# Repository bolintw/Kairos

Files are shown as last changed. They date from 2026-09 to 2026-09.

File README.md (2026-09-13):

# Kairos

<p align="center">
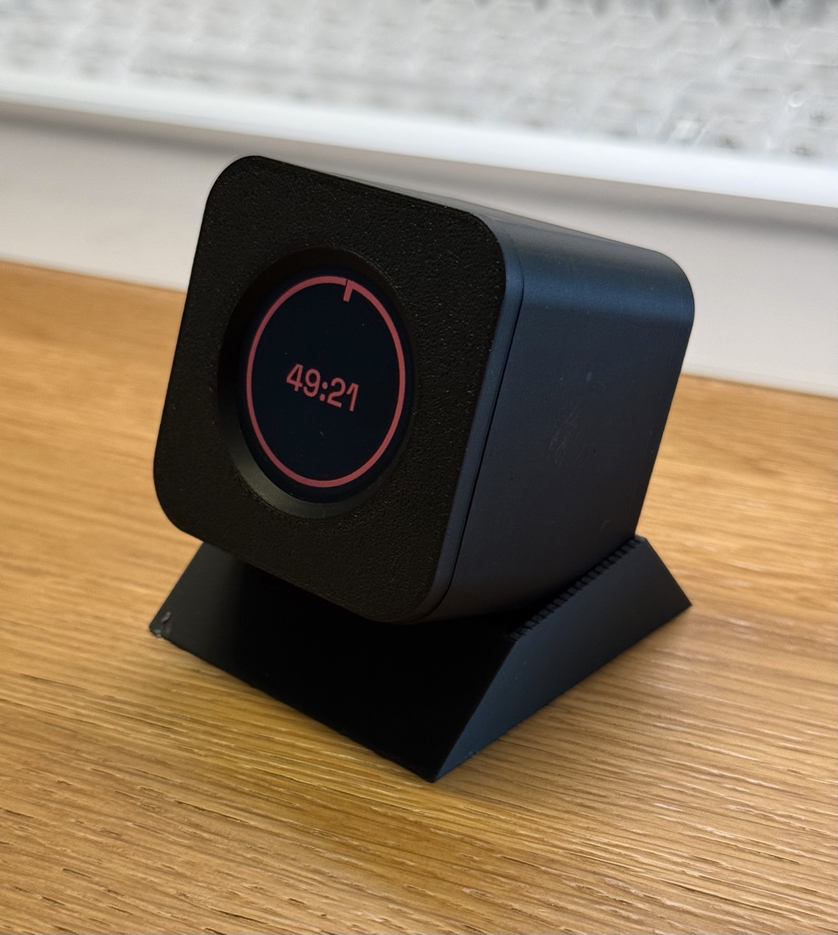
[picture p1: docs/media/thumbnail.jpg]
Kairos on a desk
  
</p>

A gravity-triggered desktop Pomodoro / countdown timer. No buttons for the
core interaction — flip the device to a different face to switch what it's
timing, tap it to start or pause. Built on a Waveshare ESP32-S3-LCD-1.28
round display, in modern C++ on ESP-IDF.

Kairos is also a personal practice ground for two things at once: getting
hands-on with embedded C++ on real hardware, and calibrating how well an AI
coding agent (Claude) holds up on a project that grows past a single
session — architecture discipline, whether its design choices survive
contact with real hardware bugs, and how to review its output in a domain
I'm not already fluent in. Every commit that's been verified on real
hardware and authored primarily by the agent is committed under
`Claude Sonnet 5 <noreply@anthropic.com>`, so that history is easy to
filter and read back later (`git log --author="Claude Sonnet 5"`).

## Faces

The device has no fixed "up" — the screen always faces you, and you rotate
it in your hand like a dial. Four quadrants each hold a different timer:

| Face | Mode |
|---|---|
| A | Pomodoro, 25 min focus / 5 min break |
| B | Pomodoro, 50 min focus / 10 min break |
| C | Stopwatch (counts up, no target duration) |
| D | Breathe — a guided 4-7-8 breathing exercise, four rounds that ramp up to the full pattern |

Rotating past a hysteresis threshold switches which face is active and
resets that face's progress. Screen brightness doubles as the notification
channel — it fades during a focus session, snaps back on any interaction,
and ramps up again as a phase is about to end — since there's no speaker or
vibration motor.

**Battery view**: not a fifth face — pick the device up and hold it tilted
out of its normal resting plane for about half a second, and the screen
swaps to a 5-segment battery gauge instead of whatever face was showing.
Set it back down (or lay it flat again) and it returns immediately. The
timer underneath keeps running the whole time.

## Controls

**Single tap** — start or pause whichever face is currently showing.

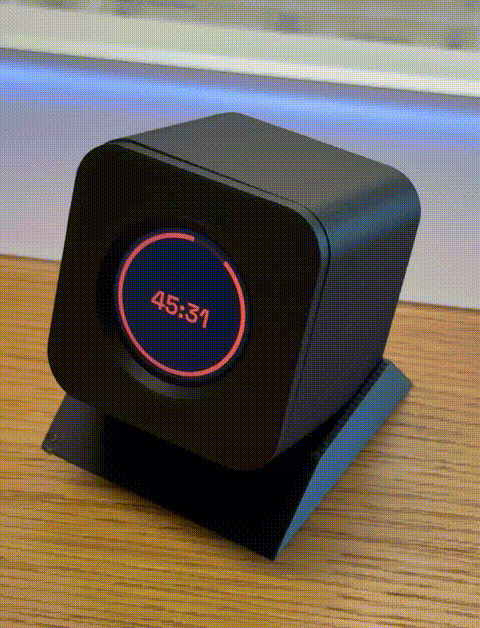
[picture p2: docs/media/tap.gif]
Tap to start/pause


**Flip** — rotate to a different face to switch what's being timed.

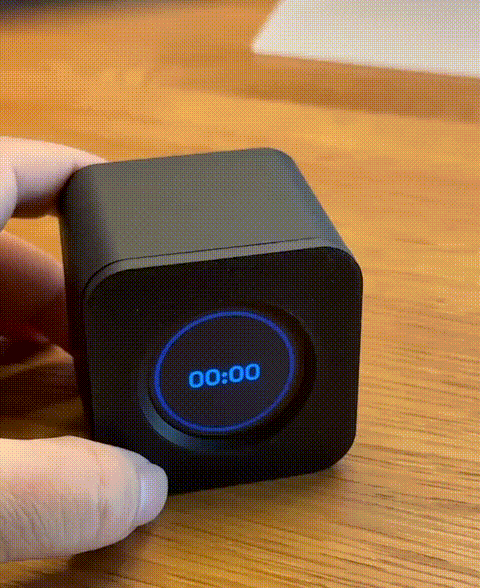
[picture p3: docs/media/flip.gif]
Flip to switch faces


**Double tap** — wakes the screen from idle sleep, a deliberate two-tap
gesture so an incidental bump won't wake it by accident.

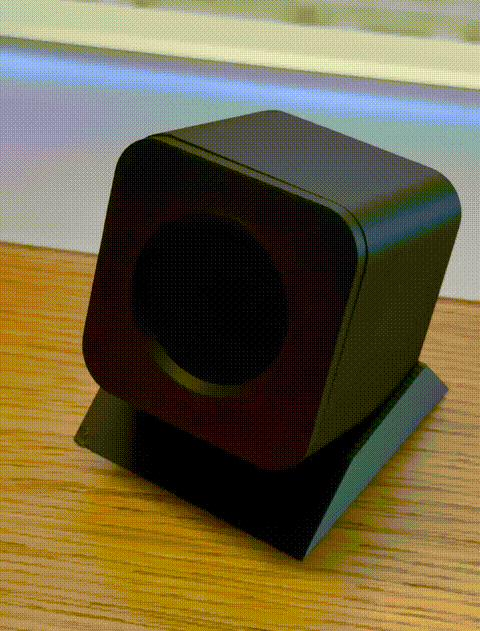
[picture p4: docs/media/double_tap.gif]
Double tap to wake from sleep


**Hold BOOT (~3s)** — enters calibration mode, while the device is already
running.

## Hardware

- [Waveshare ESP32-S3-LCD-1.28](https://www.waveshare.com/esp32-s3-lcd-1.28.htm) — round 240×240 GC9A01A SPI display, QMI8658 6-axis IMU, ESP32-S3, in one non-touch board.
- One or two 800mAh 1S LiPo cells. Two wired in parallel (~1600mAh combined) is a drop-in upgrade — electrically it's still a single 1S pack to the charger and firmware.

## Battery Life

Measured current draw:

| State | Current |
|---|---|
| Full brightness (paused / just interacted) | ~82mA |
| Dimmed (running, immersion-faded) | ~70mA |
| Idle sleep (light sleep, screen off) | ~800µA |

The firmware also runs a two-stage low-battery safety net — a forced
warning screen first, then automatic deep sleep to protect the cell from
over-discharge if it's left unattended.

Real-hardware endurance test on a single 800mAh cell, kept continuously
active the entire time (never allowed to idle-sleep — the worst case for
power draw): **10 hours 10 minutes** before the low-battery warning
triggered. Day-to-day use, dominated by light sleep between interactions,
runs considerably longer than this.

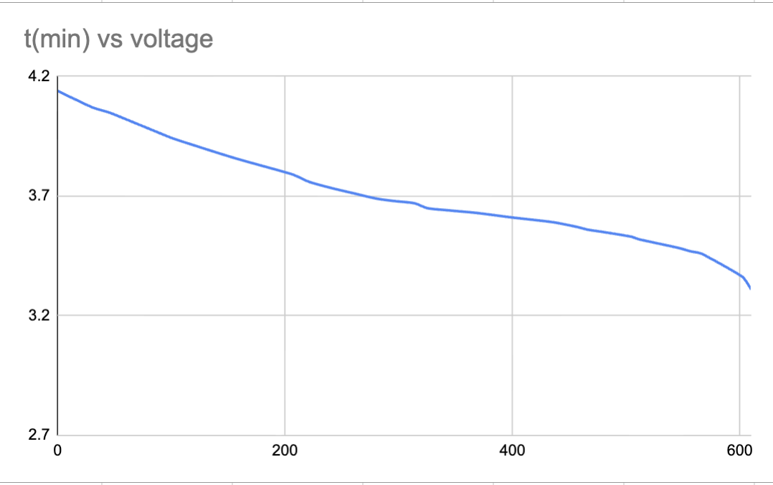
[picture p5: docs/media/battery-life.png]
Battery voltage vs. time over the 10h10m endurance test


## Assembly

Printable files: [Kairos — Gravity Timer on MakerWorld](https://makerworld.com/zh-tw/models/3299098-kairos-gravity-timer-homemade-pomodoro-cube#profileId-3744041).

What you'll need, beyond the printed front cover, back cover, and button:

- 4× M3 × 4mm heat-set threaded inserts
- 4× M3 × 5mm countersunk (flat-head) screws
- 4× strong magnets, 8mm diameter × 2mm thick

Steps:

1. Print the parts. Pause the print at the marked layer(s) to embed the
   magnets, then resume — printing everything in one job means two pauses
   in total.
2. Heat-set the four threaded inserts into the printed front cover with a
   soldering iron.
3. Connect the battery cable to the screen, then set the screen onto the
   front cover.

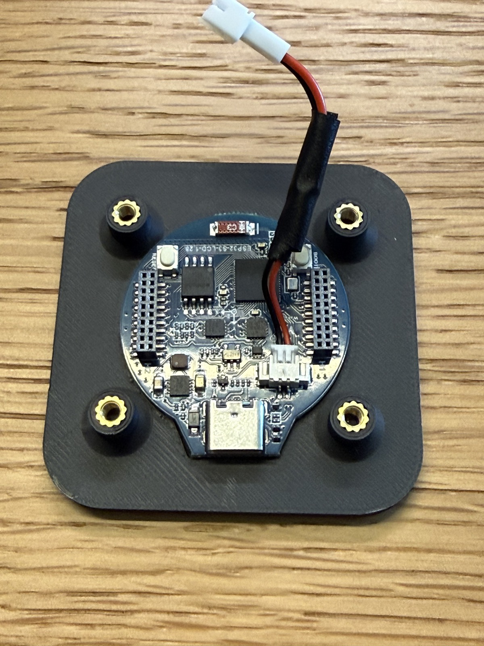
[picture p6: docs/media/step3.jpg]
Screen connected and seated on the front cover
   

4. Fit the printed button into its slot in the back cover. Flip it over
   onto the screen — the alignment tabs on either side capture the
   pin-header socket — and fasten with the four countersunk screws. Be
   careful the button doesn't fall out of place; if it helps, flip the
   screen/front-cover assembly over and lower it onto the back cover
   instead.

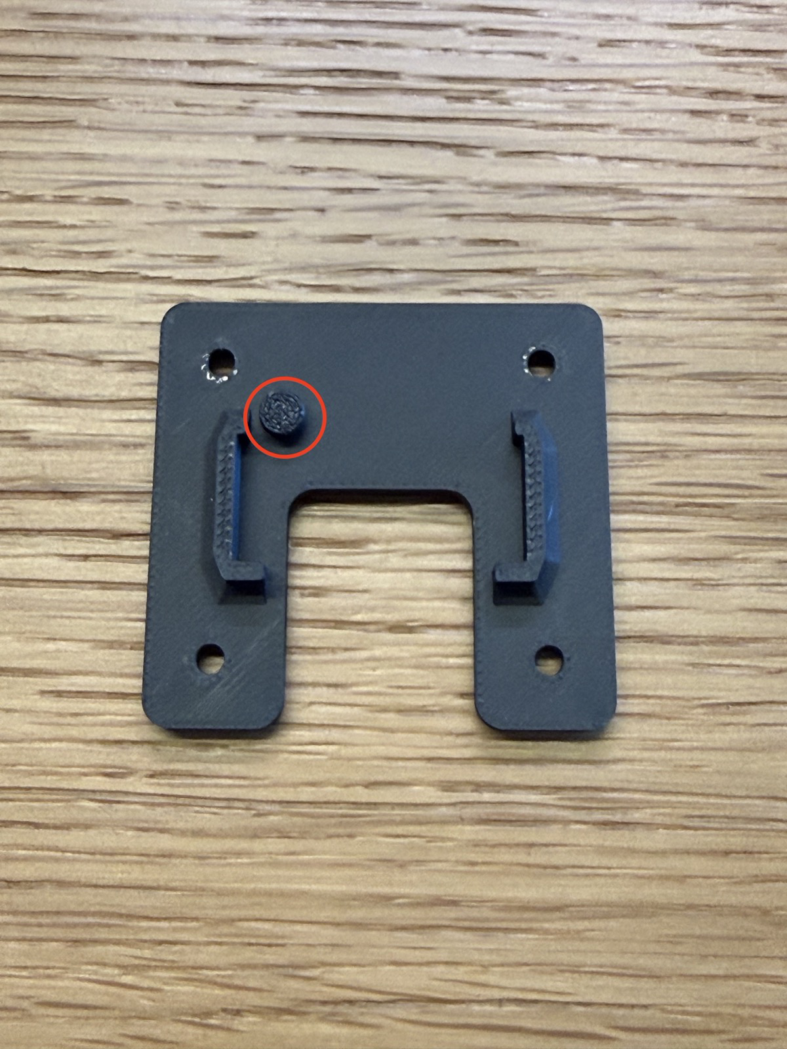
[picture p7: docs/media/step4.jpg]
Printed button seated in the back cover
   

5. Fit a battery inside the enclosure — double-sided tape works well to
   hold it in place. Use the largest capacity that still fits.

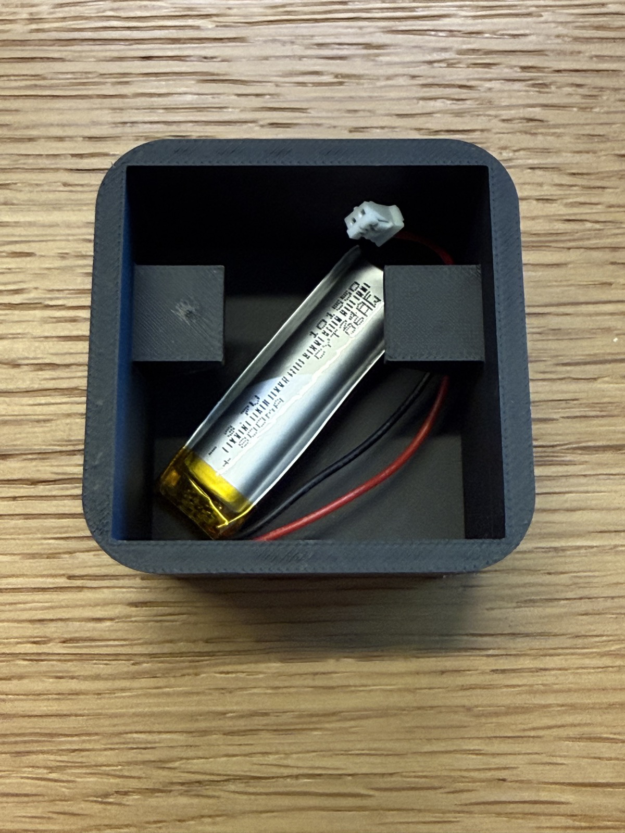
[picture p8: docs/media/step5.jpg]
Battery fitted inside the enclosure
   

6. Connect the battery, then close the front cover, aligning it to the
   magnets.

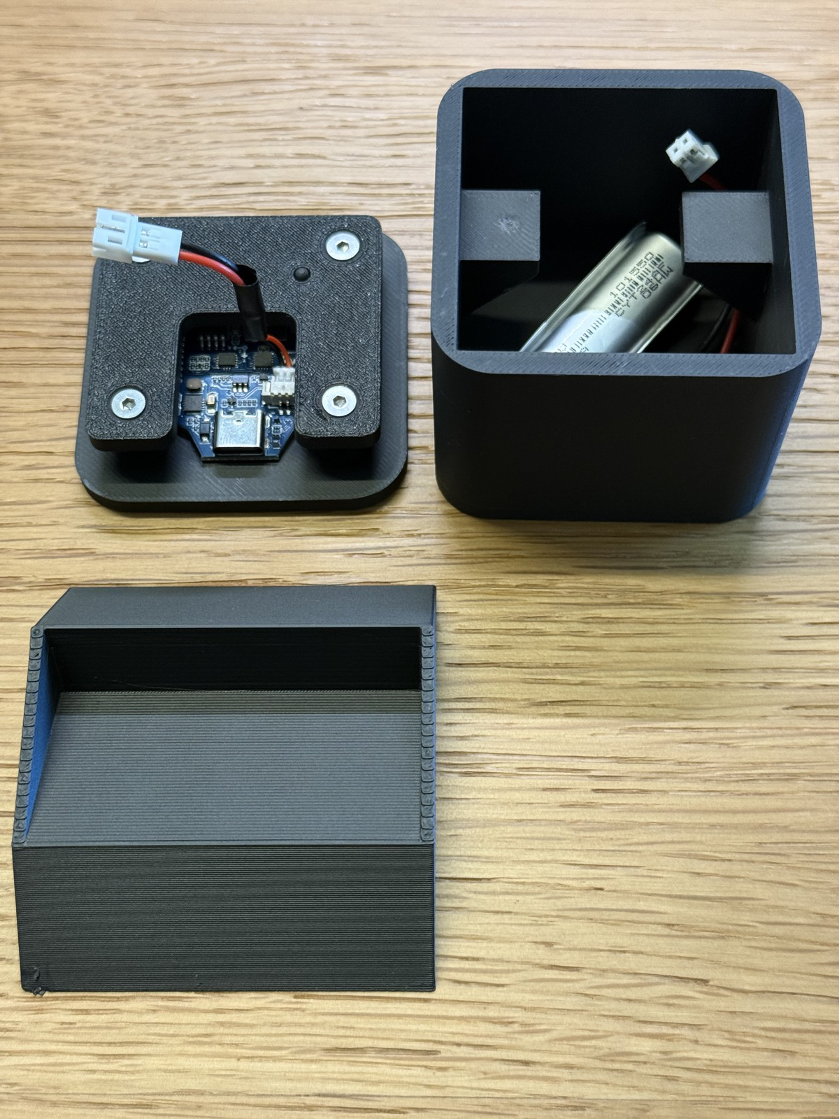
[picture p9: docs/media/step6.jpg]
Screen module, body, and front cover ready to close up
   
7. Once the screen looks correct, open the front cover, press and hold
   the calibration button, close the front cover again, and follow the
   on-screen prompts to calibrate.
8. Set it on the stand — enjoy!

## Building the Firmware

Requires [ESP-IDF](https://docs.espressif.com/projects/esp-idf/en/stable/esp32s3/get-started/index.html) v6.0 targeting `esp32s3`.

```sh
git submodule update --init --recursive
cd firmware
idf.py set-target esp32s3
idf.py build
idf.py -p <PORT> flash monitor
```

## License

[PolyForm Noncommercial 1.0.0](LICENSE) — free to use and modify for any
noncommercial purpose; commercial use is not permitted.

The primary display font is [Space Grotesk](https://github.com/floriankarsten/space-grotesk),
Copyright 2020 The Space Grotesk Project Authors, licensed under the
[SIL Open Font License 1.1](firmware/main/SpaceGrotesk-OFL.txt).

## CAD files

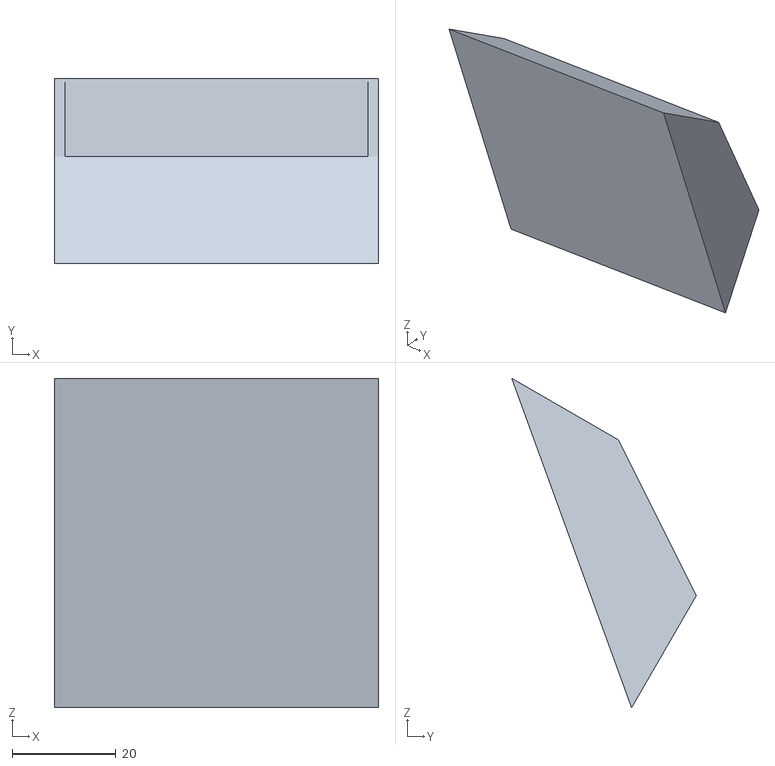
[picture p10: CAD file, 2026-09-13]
docs/printable/Stand.stl
62.4 x 35.6 x 63.5

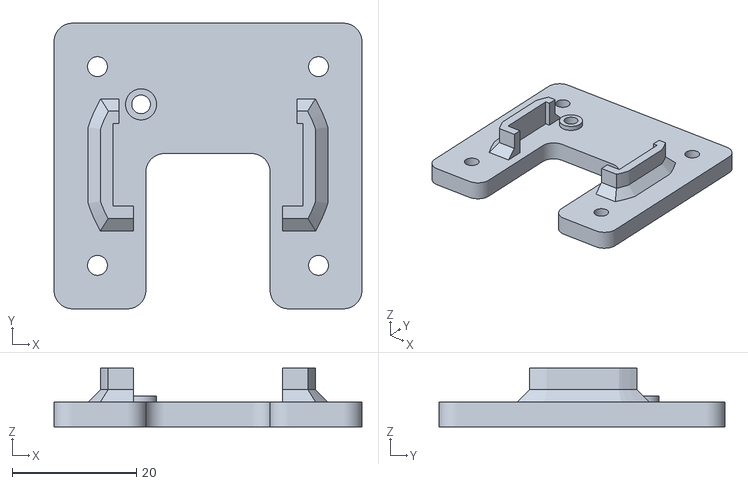
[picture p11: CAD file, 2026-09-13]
docs/printable/Display fixture.stl
49.6 x 46.0 x 9.50

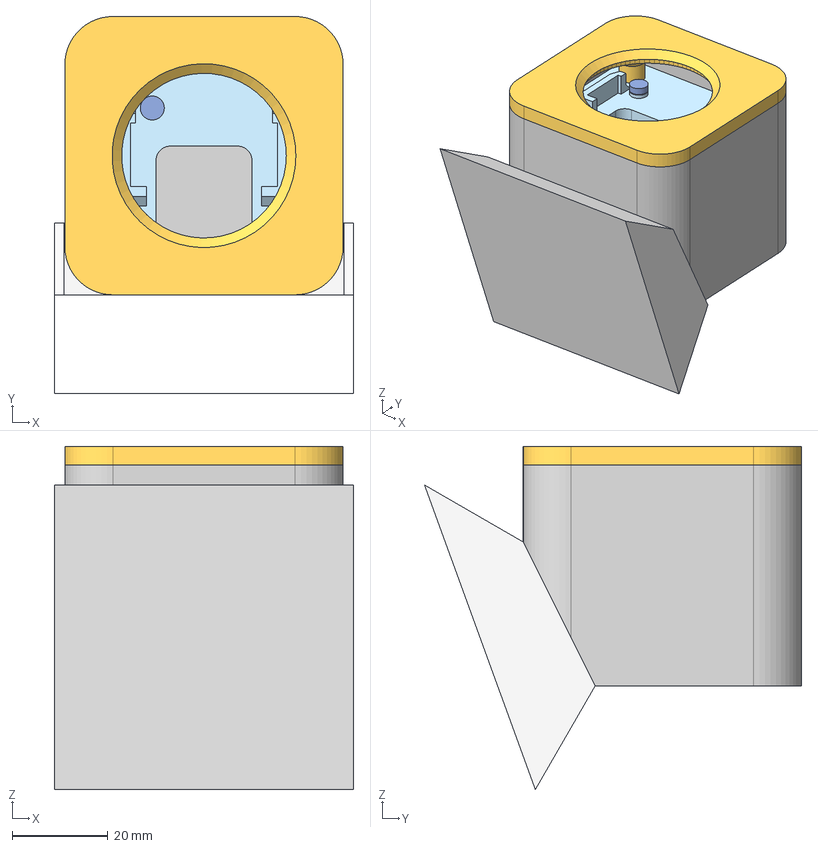
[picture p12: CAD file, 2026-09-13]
docs/printable/Kairos.step
62.4 x 78.6 x 71.5 mm

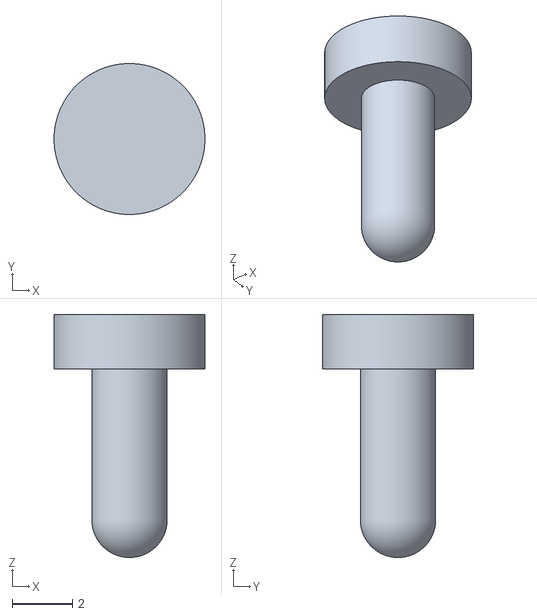
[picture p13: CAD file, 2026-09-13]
docs/printable/Button.stl
5.00 x 5.00 x 8.05

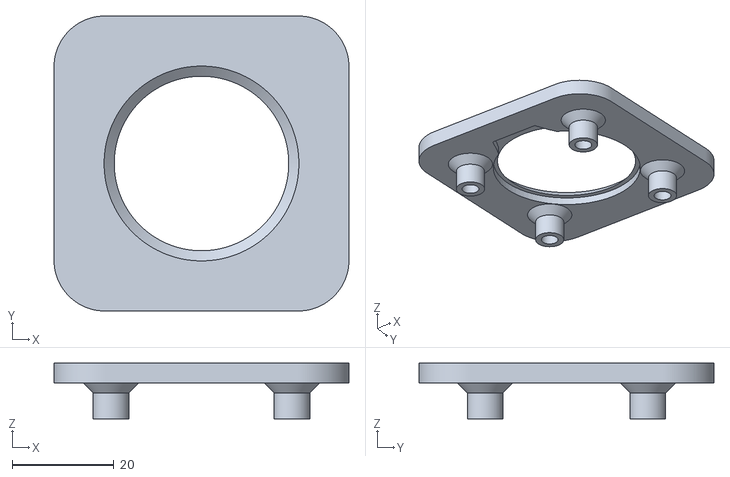
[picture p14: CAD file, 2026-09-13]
docs/printable/Front lid.stl
58.0 x 58.0 x 11.0

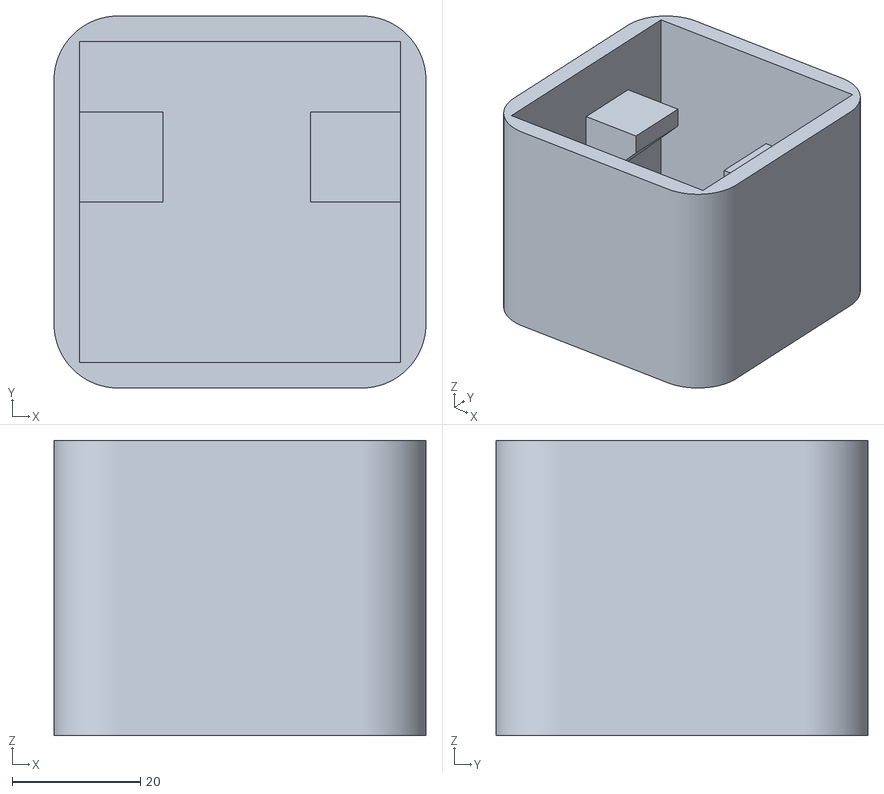
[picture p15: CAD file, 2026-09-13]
docs/printable/Box.stl
58.0 x 58.0 x 46.0

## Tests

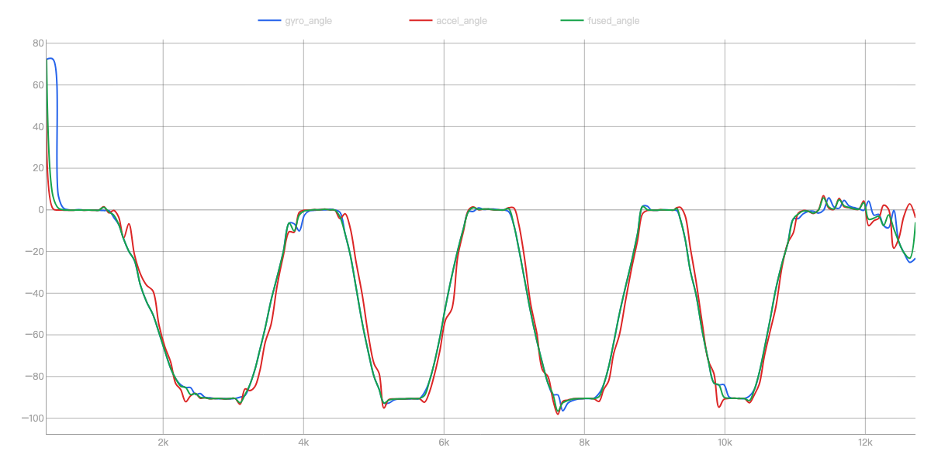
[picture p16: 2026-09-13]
docs/media/angle-test.png

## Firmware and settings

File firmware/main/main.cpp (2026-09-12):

#include <atomic>
#include <cstdint>
#include <cstdio>

#include "driver/gpio.h"
#include "esp_attr.h"
#include "esp_pm.h"
#include "esp_sleep.h"
#include "esp_timer.h"
#include "freertos/FreeRTOS.h"
#include "freertos/task.h"
#include "lvgl.h"
#include "nvs_flash.h"

#include "app_controller.hpp"
#include "attitude_estimator.hpp"
#include "battery_monitor.hpp"
#include "calibration_mode.hpp"
#include "debug_config.hpp"
#include "sleep_mode.hpp"
#include "gui_manager.hpp"
#include "i2c_scan.hpp"
#include "lgfx_config.hpp"
#include "nvs_calibration.hpp"
#include "qmi8658.hpp"

namespace {

constexpr int kLvglTickPeriodMs = 5;
// Two draw buffers enable LVGL's double-buffered partial mode: while
// chunk N is being DMA'd out over SPI, LVGL renders chunk N+1 into the
// other buffer instead of waiting.
constexpr int kDrawBufRows = 60;
// Sampling faster than what's filtered/displayed leaves headroom for the
// low-pass filters above the display's ~60fps cap. QMI8658's own ODR is
// 1000Hz and the I2C read itself is well under a millisecond, so 120Hz
// polling fits comfortably in the 5ms main-loop cadence.
constexpr int64_t kSensorUpdatePeriodUs = 1000000 / 120;  // ~120Hz

// A voltage reading has no reason to be as fresh as attitude — voltage
// drifts on a minutes scale, and BatteryMonitor::ReadVoltage() already
// blocks for kNumSamples (32) raw ADC reads per call.
constexpr int64_t kBatteryReadPeriodUs = 10 * 1000000;  // 0.1Hz

// Stage 2 of the low-battery safety net — see app_controller.hpp design
// note 11 for stage 1 (the warning screen, down to kLowBatteryEnterV).
// Below this second, lower threshold, refuse to keep running at all:
// forced deep sleep instead of the normal light-sleep+WoM loop — see the
// idle-sleep block below. Enter threshold is
// AppController::kCriticalBatteryEnterV (3.0V), read from there rather
// than duplicated here so the two constants can't drift apart.
//
// Exit threshold is set far above entry (3.8V, not e.g. 3.2V) because a
// LiPo's terminal voltage jumps up a real step the instant charging
// current starts flowing, before any meaningful capacity has gone back
// in (internal-resistance IR drop, not state of charge — and a degraded
// cell's higher internal resistance makes this jump bigger, not
// smaller). A narrow gap risks reading that transient alone as
// "recovered" and resuming full active operation while the battery's
// real stored energy has barely moved.
constexpr float kCriticalBatteryExitV = 3.8f;
// Deep sleep current is tiny (~8uA) next to a brief active-boot check,
// so this can afford to be fairly frequent.
constexpr uint64_t kCriticalBatteryCheckPeriodUs = 30ULL * 1000 * 1000;

// Hides the debug overlay (angle/taps/is_moving label) without deleting
// the code.
constexpr bool kDebugOverlayEnabled = kDebugEnabled;

// One live "ATT," CSV line per sensor tick with AttitudeEstimator's
// gyro-only angle, accel-only angle, fused angle, and gz.
constexpr bool kAttitudeDebugLogEnabled = false;

// Hold BOOT (GPIO0) this long, while the app is already running, to enter
// calibration mode. NOT checked at power-on/reset — see calibration_mode.hpp.
constexpr int64_t kCalibrationHoldUs = 3 * 1000 * 1000;

// Tap Engine config — see qmi8658.hpp's ConfigureTap() for what each
// parameter means. The idle-sleep path (Qmi8658::SetLowPowerAccelOnly())
// deliberately leaves the accel ODR these were tuned against unchanged,
// so these same values keep applying whether or not gyro is enabled.
constexpr uint8_t kTapPriority = 0;
constexpr uint8_t kTapPeakWindow = 40;
constexpr uint16_t kTapTapWindow = 100;
constexpr uint16_t kTapDTapWindow = 500;
constexpr float kTapAlpha = 0.0625f;
constexpr float kTapGamma = 0.25f;
constexpr float kTapPeakMagThr = 0.8f;
constexpr float kTapUdmThr = 0.4f;

// Wake-on-Motion config for idle sleep — see qmi8658.hpp's
// EnterWakeOnMotion(). kWomThresholdMg is maxed out at the register's
// 255 ceiling — even there, WoM wakes on any sufficiently large
// accelerometer slope, not specifically a deliberate tap (see that
// method's trade-off note), which is why the two-stage confirm below
// exists as a software-side filter on top. kWomBlankingSamples is also
// maxed (6-bit field, max 63, ~63ms at 1000Hz accel ODR) to absorb the
// transient STATUS1 latch that toggling CTRL7 on mode entry can cause.
constexpr uint8_t kWomThresholdMg = 255;
constexpr uint8_t kWomBlankingSamples = 63;

// Two-stage WoM wake confirmation — see the idle-sleep block's own
// comment. A deliberate double-tap-to-wake gesture, not just a debounce:
// a single physical tap only ever registers on whichever detector is
// active at that instant (WoM, since the tap engine isn't running during
// light sleep), so this window waits for a genuinely separate second
// tap. 1500ms gives a natural two-tap rhythm enough room, confirmed
// reliable both bare-board and inside the finished enclosure.
constexpr int kWomConfirmWindowMs = 1500;
constexpr int kWomConfirmPollMs = 20;

// Measures the real elapsed time from RunIdleSleep() returning to the
// confirm-window poll loop starting — the cost of
// ExitWakeOnMotion()+ConfigureTap()+the spurious-latch discard.
constexpr bool kWomConfirmLatencyLogEnabled = kDebugEnabled;

static LGFX lcd;
static uint8_t lvgl_draw_buf1[240 * kDrawBufRows * 2];  // RGB565, 2 bytes/px
static uint8_t lvgl_draw_buf2[240 * kDrawBufRows * 2];

int64_t g_lvgl_flush_accum_us = 0;
uint32_t g_lvgl_flush_call_count = 0;

void lvgl_flush_cb(lv_display_t* disp, const lv_area_t* area, uint8_t* px_map)
{
    const int32_t w = area->x2 - area->x1 + 1;
    const int32_t h = area->y2 - area->y1 + 1;
    const int64_t flush_start_us = esp_timer_get_time();
    // Display is configured LV_COLOR_FORMAT_RGB565_SWAPPED to match the
    // byte order pushImage() expects.
    //
    // pushImageDMA() + waitDMA(): with two draw buffers, LVGL alternates
    // between them each flush, so while this chunk's bytes are still
    // going out over SPI, LVGL can render the next chunk into the other
    // buffer instead of blocking. waitDMA() at the top, not the bottom,
    // blocks only on the *previous* transfer if it hasn't finished yet —
    // this call's own transfer is left running and collected by the next
    // call's waitDMA() instead.
    lcd.waitDMA();
    lcd.pushImageDMA(area->x1, area->y1, w, h, reinterpret_cast<uint16_t*>(px_map));
    g_lvgl_flush_accum_us += esp_timer_get_time() - flush_start_us;
    ++g_lvgl_flush_call_count;
    lv_display_flush_ready(disp);
}

void lvgl_tick_cb(void*)
{
    lv_tick_inc(kLvglTickPeriodMs);
}

// LVGL's default builtin sprintf doesn't implement %f (it silently drops
// the conversion and leaves the literal 'f' character), so format floats
// as fixed-point integers ourselves rather than depend on a float-capable
// sprintf/libc combination.
int RoundToFixed(float value, int scale)
{
    return static_cast<int>(value * scale + (value >= 0 ? 0.5f : -0.5f));
}

// Splits a fixed-point value into sign + whole + fractional digits for
// display. Needed because plain `fixed / scale` truncates toward zero:
// for fixed=-85, scale=100, that gives whole=0 with no sign information
// left in it, so "%+d" on the whole part alone prints "+0" — silently
// hiding the sign on every reading with magnitude under 1.0. Splitting
// off the sign before dividing the (now always non-negative) magnitude
// avoids that.
struct FixedParts { char sign; int whole; int frac; };

FixedParts SplitFixed(int fixed, int scale)
{
    const int mag = fixed < 0 ? -fixed : fixed;
    return FixedParts{fixed < 0 ? '-' : '+', mag / scale, mag % scale};
}

// AttitudeEstimator deliberately doesn't include qmi8658.hpp (no
// hardware/I2C knowledge, so it stays host-testable), so its Sample type
// is distinct from Qmi8658::Sample even though the fields line up —
// convert explicitly at the call site instead.
AttitudeEstimator::Sample ToAttitudeSample(const Qmi8658::Sample& s)
{
    AttitudeEstimator::Sample out;
    out.accel_g[0] = s.accel_g[0];
    out.accel_g[1] = s.accel_g[1];
    out.accel_g[2] = s.accel_g[2];
    out.gyro_dps[0] = s.gyro_dps[0];
    out.gyro_dps[1] = s.gyro_dps[1];
    out.gyro_dps[2] = s.gyro_dps[2];
    return out;
}

// Diagnostic, off by default: switches the IMU into WoM mode for
// kWomEdgeTestDurationMs, watches both IMU_INT1/IMU_INT2 with plain
// edge-triggered ISRs, and dumps every transition's pin/level/timestamp —
// useful if WoM ever needs re-diagnosing (see RunIdleSleep() for the
// actual sleep/wake path in normal operation).
constexpr bool kRunWomEdgeTestOnBoot = false;
constexpr gpio_num_t kWomEdgeTestInt1Gpio = GPIO_NUM_47;
constexpr gpio_num_t kWomEdgeTestInt2Gpio = GPIO_NUM_48;
constexpr uint32_t kWomEdgeTestDurationMs = 15000;
constexpr size_t kWomEdgeTestMaxEvents = 256;

struct WomEdgeEvent {
    int64_t t_us;
    gpio_num_t gpio;
    int level;
};
WomEdgeEvent g_wom_edge_events[kWomEdgeTestMaxEvents];
std::atomic<size_t> g_wom_edge_write_idx{0};

void IRAM_ATTR WomEdgeIsr(void* arg)
{
    const gpio_num_t gpio = static_cast<gpio_num_t>(reinterpret_cast<intptr_t>(arg));
    const size_t idx = g_wom_edge_write_idx.fetch_add(1, std::memory_order_relaxed);
    if (idx < kWomEdgeTestMaxEvents) {
        g_wom_edge_events[idx].t_us = esp_timer_get_time();
        g_wom_edge_events[idx].gpio = gpio;
        g_wom_edge_events[idx].level = gpio_get_level(gpio);
    }
}

void RunWomEdgeTest(Qmi8658& imu)
{
    for (gpio_num_t gpio : {kWomEdgeTestInt1Gpio, kWomEdgeTestInt2Gpio}) {
        gpio_config_t cfg = {};
        cfg.pin_bit_mask = 1ULL << gpio;
        cfg.mode = GPIO_MODE_INPUT;
        cfg.intr_type = GPIO_INTR_ANYEDGE;
        gpio_config(&cfg);
    }
    gpio_install_isr_service(0);
    gpio_isr_handler_add(kWomEdgeTestInt1Gpio, WomEdgeIsr, reinterpret_cast<void*>(kWomEdgeTestInt1Gpio));
    gpio_isr_handler_add(kWomEdgeTestInt2Gpio, WomEdgeIsr, reinterpret_cast<void*>(kWomEdgeTestInt2Gpio));

    imu.EnterWakeOnMotion(kWomThresholdMg, kWomBlankingSamples);
    printf("WOM_EDGE_TEST: started, %lus window, tap/move the device now — not entering sleep, watching both INT1(47) and INT2(48)\n",
           static_cast<unsigned long>(kWomEdgeTestDurationMs / 1000));

    // Deliberately just waits — no I2C traffic to this device for the
    // whole window, see the class comment for why.
    vTaskDelay(pdMS_TO_TICKS(kWomEdgeTestDurationMs));

    gpio_isr_handler_remove(kWomEdgeTestInt1Gpio);
    gpio_isr_handler_remove(kWomEdgeTestInt2Gpio);
    imu.ExitWakeOnMotion();
    imu.ConfigureTap(kTapPriority, kTapPeakWindow, kTapTapWindow, kTapDTapWindow, kTapAlpha, kTapGamma,
                      kTapPeakMagThr, kTapUdmThr);
    (void)imu.PollTapEvent();  // discard the same CTRL7/CTRL8-toggle spurious latch ConfigureTap() always produces

    size_t count = g_wom_edge_write_idx.load(std::memory_order_relaxed);
    const bool overflowed = count > kWomEdgeTestMaxEvents;
    if (overflowed) count = kWomEdgeTestMaxEvents;
    printf("WOM_EDGE_TEST: done, %zu edge(s) captured%s\n", count, overflowed ? " (buffer overflowed, some dropped)" : "");
    for (size_t i = 0; i < count; ++i) {
        printf("WOM_EDGE,i=%zu,t_us=%lld,gpio=%d,level=%d\n", i, static_cast<long long>(g_wom_edge_events[i].t_us),
               static_cast<int>(g_wom_edge_events[i].gpio), g_wom_edge_events[i].level);
    }
}

}  // namespace

extern "C" void app_main(void)
{
    // GPIO0 (BOOT) as a normal input once past the ROM bootloader's
    // strapping check — see calibration_mode.hpp for why this is only
    // polled here, not checked at reset. Configured before the
    // critical-battery escape hatch below so it can share this call.
    gpio_config_t boot_btn_cfg = {};
    boot_btn_cfg.pin_bit_mask = 1ULL << GPIO_NUM_0;
    boot_btn_cfg.mode = GPIO_MODE_INPUT;
    boot_btn_cfg.pull_up_en = GPIO_PULLUP_ENABLE;
    gpio_config(&boot_btn_cfg);

    // Stage 2's periodic recheck. Deep sleep is a full reboot, not a
    // resume — app_main() runs again from scratch, and RTC memory (this
    // flag's storage class) is the only thing that survives it, which is
    // how a fresh boot tells "woken to re-check critical battery" apart
    // from a normal boot. Checked before any of the heavier LCD/LVGL/IMU
    // init below, and kept minimal when it IS a recheck, so a cycle that
    // goes back to sleep costs as little active time as possible.
    static RTC_DATA_ATTR bool in_critical_battery_sleep = false;
    if (in_critical_battery_sleep && esp_sleep_get_wakeup_cause() == ESP_SLEEP_WAKEUP_TIMER) {
        // Escape hatch: hold BOOT through a wake to force a real boot
        // regardless of voltage. Exists because a bug in this still-new
        // mechanism could otherwise strand the device in an
        // indefinite sleep-reboot-sleep loop with no way back in short of
        // reflashing (which itself needs a real boot to reach the
        // download-mode entry point) — same "don't want a firmware bug to
        // look like a bricked device" reasoning as design note 9's
        // double-tap wake, one level more serious here since deep sleep
        // exits this whole function rather than just a loop inside it.
        const bool boot_held = gpio_get_level(GPIO_NUM_0) == 0;
        if (!boot_held) {
            BatteryMonitor critical_battery_monitor;
            const float v = critical_battery_monitor.ReadVoltage();
            // Always-on, not gated behind kDebugEnabled (debug_config.hpp)
            // — this is a new, higher-stakes mechanism (a real reboot
            // cycle) worth being able to see regardless of the general
            // debug flag state, same reasoning qmi8658.hpp gives for
            // always printing real errors. Plain %.2f, not the LVGL
            // fixed-point workaround main.cpp's on-screen label needs
            // (LVGL's own lightweight sprintf doesn't support %f) — this
            // goes to the serial console's real printf, which already
            // uses %f elsewhere in this file (see the ATT log above).
            printf("CRITICAL_BATTERY_RECHECK,v=%.2fV\n", v);
            if (v < kCriticalBatteryExitV) {
                esp_sleep_enable_timer_wakeup(kCriticalBatteryCheckPeriodUs);
                esp_deep_sleep_start();  // never returns
            }
            printf("CRITICAL_BATTERY_RECOVERED — resuming normal boot\n");
            // else: voltage recovered — fall through to a real boot below.
        } else {
            printf("CRITICAL_BATTERY_ESCAPE_HATCH — BOOT held, forcing a real boot\n");
        }
        in_critical_battery_sleep = false;
    }

    printf("Kairos gravity timer — hello from C++\n");

    esp_err_t nvs_err = nvs_flash_init();
    if (nvs_err == ESP_ERR_NVS_NO_FREE_PAGES || nvs_err == ESP_ERR_NVS_NEW_VERSION_FOUND) {
        nvs_flash_erase();
        nvs_err = nvs_flash_init();
    }
    if (nvs_err != ESP_OK) {
        printf("nvs_flash_init failed: %d\n", nvs_err);
    }

    CalibrationData calibration;
    if (!LoadCalibration(calibration)) {
        printf("No saved calibration — using uncalibrated defaults until "
               "RunCalibrationMode() is run once (hold BOOT ~3s)\n");
    }

    lcd.init();
    lcd.setBrightness(255);  // full bright at boot; AppController takes over from here
    printf("LCD initialized, backlight on (GPIO40 via PWM)\n");

    RunI2cScan();

    lv_init();

    lv_display_t* disp = lv_display_create(240, 240);
    lv_display_set_flush_cb(disp, lvgl_flush_cb);
    // LovyanGFX's pushImage() expects SPI-panel byte order, which is
    // swapped relative to LVGL's plain RGB565. Without this, only pure
    // black/white survive untouched; every anti-aliased/blended pixel
    // (i.e. most of any glyph's edges) comes out with a scrambled hue.
    lv_display_set_color_format(disp, LV_COLOR_FORMAT_RGB565_SWAPPED);
    lv_display_set_buffers(disp, lvgl_draw_buf1, lvgl_draw_buf2, sizeof(lvgl_draw_buf1),
                            LV_DISPLAY_RENDER_MODE_PARTIAL);

    const esp_timer_create_args_t tick_timer_args = {
        .callback = &lvgl_tick_cb,
        .arg = nullptr,
        .dispatch_method = ESP_TIMER_TASK,
        .name = "lvgl_tick",
        .skip_unhandled_events = false,
    };
    esp_timer_handle_t tick_timer;
    esp_timer_create(&tick_timer_args, &tick_timer);
    esp_timer_start_periodic(tick_timer, kLvglTickPeriodMs * 1000);

    // min_freq_mhz == max_freq_mhz deliberately disables DFS (dynamic CPU
    // frequency scaling) — even a brief automatic drop below 160MHz
    // measurably hurt the software screen-rotation redraw's throughput.
    esp_pm_config_t pm_config = {};
    pm_config.max_freq_mhz = 160;
    pm_config.min_freq_mhz = 160;
    pm_config.light_sleep_enable = true;
    esp_pm_configure(&pm_config);

    // Black background — the default LVGL theme is light, which clashes
    // once AppController starts dimming/warming the primary label's color.
    lv_obj_set_style_bg_color(lv_screen_active(), lv_color_black(), 0);
    lv_obj_set_style_bg_opa(lv_screen_active(), LV_OPA_COVER, 0);

    printf("LVGL running\n");
    if (kAttitudeDebugLogEnabled) {
        printf("ATT,t_ms,gz_dps,gyro_angle,accel_angle,fused_angle,is_moving,in_valid_plane\n");
    }

    // Deliberately not rotating with the primary label (see
    // gui_manager.hpp's screen counter-rotation note) — a plain fixed
    // child of lv_screen_active(). Created before GuiManager below so
    // root_'s children end up later in lv_screen_active()'s child list
    // and draw on top of this overlay, not under it.
    lv_obj_t* label = nullptr;
    if (kDebugOverlayEnabled) {
        label = lv_label_create(lv_screen_active());
        lv_obj_set_style_text_font(label, &lv_font_montserrat_14, 0);
        lv_obj_set_style_text_align(label, LV_TEXT_ALIGN_CENTER, 0);
        lv_obj_set_style_text_color(label, lv_color_white(), 0);
        lv_label_set_text(label, "waiting for IMU...");
        lv_obj_align(label, LV_ALIGN_TOP_MID, 0, 30);
    }

    // AppController owns attitude-driven face switching (via
    // AttitudeEstimator::Output, computed below) plus tap routing and
    // TimerFace lifecycle. See app_controller.hpp for the design.
    static GuiManager gui_manager(lcd);
    static AppController app_controller(gui_manager);

    static Qmi8658 imu(GPIO_NUM_6, GPIO_NUM_7);

    // Battery-check gesture — see battery_monitor.hpp.
    static BatteryMonitor battery_monitor;

    // Starting point, not a finished tune — adjust these while watching
    // the tap count below and re-flashing. Windows are ported from
    // SensorLib's deprecated tap example (peak_window=20, tap_window=50,
    // d_tap_window=250, "@500Hz ODR"); doubled here since our accel ODR is
    // 1000Hz, to keep roughly the same real-time windows. alpha/gamma and
    // the g^2 thresholds are that example's values, unchanged (ODR-independent).
    imu.ConfigureTap(kTapPriority, kTapPeakWindow, kTapTapWindow, kTapDTapWindow,
                      kTapAlpha, kTapGamma, kTapPeakMagThr, kTapUdmThr);
    // Toggling Ctrl7/Ctrl8 while configuring the tap engine latches a
    // spurious STATUS1 tap flag (observed as "Taps 1" right at boot, with
    // no physical tap). Discard it here so the count starts clean.
    (void)imu.PollTapEvent();

    if (kRunWomEdgeTestOnBoot) {
        RunWomEdgeTest(imu);  // blocks ~15s — see its own comment
    }

    static AttitudeEstimator attitude_estimator(calibration.face_a_offset_deg, calibration.accel_bias_g[0],
                                                 calibration.accel_bias_g[1]);
    {
        // Gyro bias comes from the saved calibration (see
        // RunCalibrationMode), not a fresh live read here: this device
        // has no real power-cycle in normal use (battery + deep sleep),
        // and any wake is tap-triggered, so "assume stationary right
        // now" doesn't hold reliably enough for a live measurement.
        AttitudeEstimator::Sample bias_sample{};
        bias_sample.gyro_dps[0] = calibration.gyro_bias_dps[0];
        bias_sample.gyro_dps[1] = calibration.gyro_bias_dps[1];
        bias_sample.gyro_dps[2] = calibration.gyro_bias_dps[2];
        attitude_estimator.CalibrateGyroZeroOffset(bias_sample);
    }
    {
        // Seed angle_deg_ from a real reading instead of leaving it at
        // 0.0f — without this, booting anywhere other than face A's
        // reference orientation (e.g. plugged in via USB-C while resting
        // on face D) starts a full-size error that only closes at the
        // complementary filter's normal per-tick rate, visible as
        // "takes a moment to reach the right angle" right after flashing.
        Qmi8658::Sample seed_sample;
        if (imu.Read(seed_sample)) {
            attitude_estimator.SeedInitialAngle(ToAttitudeSample(seed_sample));
        }
    }

    int64_t next_sensor_update_us = 0;
    int64_t last_sensor_update_us = esp_timer_get_time();
    int64_t next_battery_read_us = 0;
    float last_battery_voltage_v = 0.0f;  // shown in the debug overlay below — 0 until the first real read
    int64_t boot_button_press_start_us = 0;
    int tap_count = 0;
    // Antialiasing off while actively rotating (not worth its per-pixel
    // cost during a fast flip), on once settled — dirty-checked so it's
    // only set on an actual is_moving transition, not every tick.
    bool antialiasing_enabled = true;

    int64_t last_fps_calc_us = esp_timer_get_time();
    uint32_t fps_display = 0;
    uint32_t last_update_count = 0;
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

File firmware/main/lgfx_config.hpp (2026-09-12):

#pragma once

#define LGFX_USE_V1
#include <LovyanGFX.hpp>

// Waveshare ESP32-S3-LCD-1.28 (Non-Touch): GC9A01A driving a 240x240
// round panel over SPI. Pin values from hardware_pinout.md.
//
// Backlight (GPIO40) is driven via LovyanGFX's built-in Light_PWM
// controller for real analog dimming (fade/breathing-pulse brightness
// notifications). Channel 7 avoids the low channels LovyanGFX's own
// SPI/DMA setup might touch.
class LGFX : public lgfx::LGFX_Device {
public:
    lgfx::Panel_GC9A01 _panel_instance;
    lgfx::Bus_SPI _bus_instance;
    lgfx::Light_PWM _light_instance;

    LGFX(void) {
        {
            auto cfg = _bus_instance.config();
            cfg.spi_host = SPI2_HOST;
            cfg.spi_mode = 0;
            cfg.freq_write = 80000000;  // panel supports 80MHz per hardware_pinout.md
            cfg.freq_read = 16000000;
            cfg.spi_3wire = false;
            cfg.use_lock = true;
            cfg.dma_channel = SPI_DMA_CH_AUTO;
            cfg.pin_sclk = 10;
            cfg.pin_mosi = 11;
            cfg.pin_miso = -1;  // not wired on this board
            cfg.pin_dc = 8;
            _bus_instance.config(cfg);
            _panel_instance.setBus(&_bus_instance);
        }
        {
            auto cfg = _panel_instance.config();
            cfg.pin_cs = 9;
            cfg.pin_rst = 12;
            cfg.pin_busy = -1;
            cfg.panel_width = 240;
            cfg.panel_height = 240;
            cfg.offset_x = 0;
            cfg.offset_y = 0;
            cfg.offset_rotation = 0;
            cfg.readable = false;  // no MISO wired
            cfg.invert = true;  // GC9A01 panels commonly need color inversion
            cfg.rgb_order = false;
            cfg.dlen_16bit = false;
            cfg.bus_shared = false;
            _panel_instance.config(cfg);
        }
        {
            auto cfg = _light_instance.config();
            cfg.pin_bl = 40;
            cfg.invert = false;
            cfg.freq = 44100;
            cfg.pwm_channel = 7;
            _light_instance.config(cfg);
            _panel_instance.setLight(&_light_instance);
        }
        setPanel(&_panel_instance);
    }
};

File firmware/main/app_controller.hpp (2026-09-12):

#pragma once

#include <memory>

#include "attitude_estimator.hpp"
#include "gui_manager.hpp"
#include "timer_face.hpp"

// Owns face-switching (hysteresis + Factory), brightness/ring
// notifications, idle sleep, and the battery-check/low-battery screens.
//
// Design:
//
// 1. Quantizes screen_angle_deg into A/B/C/D, centered on -90/0/90/180.
//    A=PomodoroFace(25,5), B=PomodoroFace(50,10), C=StopwatchFace,
//    D=BreathFace (see CreateFace). QuantizeFace() is stateful hysteresis:
//    it only leaves current_face_ once the angle is more than
//    kFaceHysteresisLeaveDeg past current_face_'s own center, and only
//    returns once within (90-kFaceHysteresisLeaveDeg) of the target's
//    center — avoids flip-flopping near a boundary from resting noise.
//
// 2. A face commit (onExit/onEnter) fires the instant the quantized face
//    disagrees with current_face_, moving or not — QuantizeFace's own
//    hysteresis is enough proof real movement happened. A fast swipe
//    that passes through a face's zone on the way to another commits
//    (and resets) that passed-through face too.
//
// 3. Taps are forwarded unconditionally, not gated on is_moving — a tap
//    landing mid-flip just toggles the pre-flip face and gets
//    overwritten by onEnter()'s reset if a genuine flip is confirmed.
//
// 4. `current_` is not expected to be null in normal operation.
//
// 5. Brightness/notification state machine, driven off TimerFace::Status
//    each tick plus attitude.is_moving — an `interacting` flag folds
//    tapping, flipping, and idle rotation together:
//      - face entry: snap to full bright
//      - interacting while running: snap to full bright, restart the
//        ~10s fade toward the dimmed level
//      - break phase: stays fully bright for the whole phase, no fade
//      - last ~30s of a focus-like phase: ramps UP to full bright within
//        ~3s and holds until the phase changes, not interrupted by
//        movement
//      - interacting while paused: snap to full bright, restart the
//        idle-sleep countdown
//      - paused with no interaction for kIdlePreDimHoldMs: fast-fade to
//        off over kIdleFadeToOffMs, then hold off for kIdleOffHoldMs —
//        ShouldEnterIdleSleep() goes true once the whole ~18s sequence
//        elapses. main.cpp checks this every tick and, once true, calls
//        the blocking RunIdleSleep() then NotifyWokeFromIdleSleep().
//    TimerFace/AttitudeEstimator have no notion of brightness.
//
// 6. Tap mute window: OnTap() is ignored for kTapMuteAfterSwitchMs after
//    a face switch commits — a flip often lands with residual wobble
//    that would otherwise immediately start the timer on the face just
//    arrived at. Armed only on a face-switch commit (not on any
//    is_moving blip — a light tap alone can cross that threshold too),
//    and only counts down while !attitude.is_moving. Orthogonal to the
//    tap engine's own detection windows in main.cpp's ConfigureTap call.
//
// 7. Outer progress ring, a second notification channel alongside
//    brightness. Visible arc tracks progress clockwise from 12 o'clock:
//      - Countdown (Status::has_target): starts full and erodes —
//        elapsed_fraction = 1 - remaining_ms/target_ms.
//      - Count-up (Status::is_count_up): grows from empty, one
//        revolution per hour — elapsed_fraction = (elapsed_ms mod 1h)/1h.
//      - Neither flag set: ring hidden.
//    The tick mark rides the same moving-edge angle. Ring freezes (does
//    not reset) on pause — the tick signals running/paused instead, with
//    three states: fresh/unstarted (hidden), running (steady), paused
//    with real progress (hard blink, kRingBlinkHalfPeriodMs). Orientation
//    re-snaps to the current face (GuiManager::SetRingOrientation()) once
//    per face-switch commit, not every tick.
//
// 8. PomodoroFace's phase-transition caption lives entirely in
//    pomodoro_face.hpp — orthogonal to the ring above; neither knows
//    about the other.
//
// 9. Idle sleep: once ShouldEnterIdleSleep() goes true, main.cpp switches
//    the IMU into Wake-on-Motion mode and calls the blocking
//    RunIdleSleep(imu) (repeated real light sleeps), then restores the
//    tap engine and calls NotifyWokeFromIdleSleep(). Light sleep, not
//    deep sleep, so current_'s state and the fused angle are simply
//    still there on return.
//
//    WoM wakes on any sufficiently large accelerometer slope, not
//    specifically a tap, so whatever woke RunIdleSleep() is consumed
//    internally and never forwarded to OnTap() — the device always comes
//    back paused, requiring a distinct subsequent tap to resume.
//
//    Double-tap-to-wake: a WoM trigger alone doesn't wake the device —
//    it's a silent pre-wake (screen stays off) until a second, genuinely
//    separate tap lands within kWomConfirmWindowMs. Only that combination
//    calls NotifyWokeFromIdleSleep(). Resuming a paused timer from full
//    idle sleep is three taps total: two to wake the screen, one more to
//    start it.
//
// 10. Battery-check gesture: holding the device tilted out of the
//     tracked plane (AttitudeEstimator::Output::in_valid_plane false,
//     hysteresis-debounced at the source) for kBatteryViewEnterMs shows a
//     5-block gauge instead of the current face; holding it back in-plane
//     for kBatteryViewExitMs returns to normal. Not a Face:
//     showing_battery_ doesn't touch current_/current_face_ — the
//     underlying face keeps ticking, only render() is swapped
//     (GuiManager::ShowBatteryView()) and face-switch/tap logic is
//     suppressed. BatteryVoltageToFilledBlocks() (app_controller.cpp)
//     does a plain linear split of the LiPo's 3.0-4.2V usable range
//     across the 5 blocks — not lab-accurate, good enough for an
//     at-a-glance gauge. Runs its own idle-sleep timeline
//     (battery_view_idle_elapsed_ms_) so leaving the device tilted
//     doesn't keep it lit indefinitely; unlike the low-battery screen
//     below, the underlying face is left running, not force-paused.
//
// 11. Low-battery warning screen — stage 1 of the two-stage low-battery
//     safety net (stage 2, forced deep sleep, lives entirely in main.cpp
//     since it's a reboot-based mechanism with nothing for AppController
//     to own). Voltage-driven: evaluated every tick against
//     battery_voltage_v_ with its own hysteresis pair
//     (kLowBatteryEnterV/kLowBatteryExitV). showing_low_battery_ forces a
//     "please charge" screen over whatever was showing, and is NOT exempt
//     from idle-sleep the way showing_battery_ is — staying lit
//     indefinitely works against the point of the screen. Runs the same
//     bright-hold/fade/dim-hold/cut-to-off timeline as design note 5
//     against its own low_battery_idle_elapsed_ms_ counter.
//     UpdateLowBatteryHysteresis() force-pauses a running timer on entry
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

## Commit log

2026-08-22 Fix flash size config to match actual 16MB chip
    Default idf.py create-project sdkconfig assumed 2MB flash; board
    is confirmed 16MB per hardware_pinout.md, and the mismatch was
    producing an esptool warning at boot.
2026-08-22 Light up LCD backlight via GpioPin RAII wrapper
    Adds a minimal GpioPin RAII class (main/gpio_pin.hpp) and drives
    GPIO40 (LCD_BL per hardware_pinout.md) high in app_main. Kept as a
    static local since app_main's task exits after returning, and the
    destructor would otherwise reset the pin and turn the backlight
    back off.
    Required PRIV_REQUIRES esp_driver_gpio in main/CMakeLists.txt — in
    ESP-IDF v6.0 the GPIO API lives in that component rather than the
    aggregate "driver" component.
    [main.cpp]
2026-08-22 Draw a color block via LovyanGFX (GC9A01A round panel)
    Adds LovyanGFX as a git submodule pinned to tag 1.2.27 under
    firmware/components/LovyanGFX, and a custom LGFX device class
    (main/lgfx_config.hpp) configuring Bus_SPI + Panel_GC9A01 against
    the SPI pins in hardware_pinout.md (DC=8, CS=9, CLK=10, MOSI=11,
    RST=12). No MISO is wired on this board, so readable=false.
    Backlight stays on the existing GpioPin-driven GPIO40 rather than
    LGFX's own Light_PWM, to avoid two owners of the same pin.
    main.cpp now calls lcd.init() + fillScreen(TFT_RED). Confirmed on
    hardware: red renders correctly with panel invert=true.
    [lgfx_config.hpp, main.cpp]
2026-08-22 Render LVGL text on the panel, fix idle-task watchdog starvation
    Pulls lvgl/lvgl ^9.5.0 via the component manager (main/idf_component.yml,
    dependencies.lock pins the resolved 9.5.0 build). Ports LVGL onto the
    LovyanGFX device from the previous commit: lv_display_create(240,240)
    with a 20-row partial buffer, a flush_cb that hands the buffer to
    lcd.pushImage(), and an esp_timer periodic callback driving lv_tick_inc()
    every 5ms. Confirmed on hardware: a centered "Kairos" label renders
    correctly, so LVGL's RGB565 byte order lines up with what pushImage
    expects without any swap — the risk flagged in the previous commit
    didn't materialize.
    Bug found on first flash: task_wdt repeatedly killed ID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
    [main.cpp]
2026-08-22 Fix scrambled text color: set LVGL display to RGB565_SWAPPED
    Confirmed on hardware: the "Kairos" label rendered with glitchy,
    greenish-tinted strokes instead of black-on-white. Root cause is a
    byte-order mismatch between LVGL's plain RGB565 output and the byte
    order LovyanGFX's pushImage() expects for SPI panels. Pure black
    (0x0000) and pure white (0xFFFF) are byte-swap invariant, which is
    why the earlier solid-color fillScreen() test and the bulk interior
    of glyphs looked fine — but nearly every pixel along a glyph's edges
    is an anti-aliased blend, and those scrambled into random hues.
    Fixed with lv_display_set_color_format(disp,
    LV_COLOR_FORMAT_RGB565_SWAPPED), LVGL v9's built-in color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
    [main.cpp]
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2026-08-22 Add M3 debug overlay: live accel/gyro readout
    Adds Qmi8658 (main/qmi8658.hpp), a minimal accel+gyro reader.
    Register addresses, init sequence (Ctrl1/2/3/5/7), and scale factors
    are ported from Waveshare's official Arduino demo for this board
    (ESP32-S3-LCD-1.28-Demo.zip, QMI8658.cpp) rather than re-derived from
    the datasheet PDF, which isn't reliably text-extractable here.
    main.cpp replaces the M1 "Kairos" label with a live readout (AX/AY/AZ
    in g, GX/GY/GZ in dps), refreshed every 150ms — fast enough to be
    useful, not so fast it's unreadable or hammers the I2C bus for no
    reason.
    Confirmed on hardware: accel vector magnitude reads ~1g at rest as
    expected (validates the +-8g/4096-LSB-per-g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
    [main.cpp]
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2026-08-22 Fix hidden negative sign in overlay, main task stack overflow
    Two unrelated bugs found while calibrating face reference vectors:
    1. Debug overlay never showed negative accel/gyro values. Root cause:
    `fixed / scale` truncates toward zero, so e.g. fixed=-85, scale=100
    gives whole=0 with the sign gone, and "%+d" on that prints "+0" —
    silently hiding the sign whenever magnitude is under 1.0, which is
    most readings for a device just tilted on a desk. Fixed by
    splitting sign from magnitude (SplitFixed()) before dividing, so
    the sign survives regardless of the whole part's size.
    2. Device rebooted repeatedly with "stack overflow in task main"
    (crash backtrace bottomed out i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
    [main.cpp]
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2026-08-23 Add TimerFace/AppController/GuiManager, first face StopwatchFace (M6)
    First pass, deliberately scoped down: AppController hardcodes a single
    StopwatchFace to validate the tap/tick/render pipeline on hardware
    before adding attitude-driven face switching, the Factory, or NVS
    persistence (all deferred until more faces exist). GuiManager is a
    minimal LVGL wrapper — just enough for TimerFace::render() to have
    something to call; full integration (screen counter-rotation,
    brightness/hue notifications) is M7's scope.
    Also fixes a real timing bug found via hardware testing: the main
    loop was passing a fixed kLvglTickPeriodMs to AppController::Update()
    as dt_ms, assuming every iteration takes exact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
    [app_controller.hpp, gui_manager.hpp, main.cpp]
2026-08-23 Complete M6: attitude-driven face switching, PomodoroFace, hw fixes
    Adds PomodoroFace (single class parameterized by focus/break duration,
    not a subclass per variant — the two Pomodoro faces have no behavioral
    difference, only different numbers) and replaces AppController's
    hardcoded single-face first pass with real attitude-driven switching:
    AttitudeEstimator::Output::screen_angle_deg is quantized into A/B/C/D
    via a Factory (CreateFace), debounced through is_moving rather than
    separate hysteresis machinery, with reset firing only on a genuine
    settle-after-crossing-into-a-different-face (not any settle-after-
    motion) and taps forwarded unconditionally.
    Several rounds of hardware testing s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
    [app_controller.hpp, main.cpp]
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2026-08-24 Complete M8 calibration mode; fix hysteresis commit bug; add ReservedFace (D)
    - NVS-persisted calibration mode (calibration_mode.cpp/.hpp,
    nvs_calibration.cpp/.hpp): BOOT-button long-press trigger, 5s countdown,
    static gyro bias + face-A angle offset sampling, screen feedback fixed
    (RunCalibrationMode blocked lv_timer_handler entirely; chopped delays
    into ticks that call it).
    - Found and fixed a real gyro full-scale-range bug via the QMI8658C
    datasheet: CTRL3=0x43 selects +-256dps, not +-512dps as assumed;
    kGyroLsbPerDps corrected to 128.0f to match (kept +-256dps deliberately
    for lower noise, not reverted to +-512dps).
    - Complementary filter alpha retuned 0.8 -> 0.9 after the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
    [app_controller.hpp, main.cpp]
2026-08-25 Add primary-label counter-rotation; raise sensor rate to 120Hz; enable PSRAM
    - GuiManager::SetRotationDeg() counter-rotates a small root_ container
    (200x60, wraps only the primary label) so it stays upright as the
    device physically rotates. Took three hardware crashes to land safely
    — a full-screen rotating container needs a ~225KB layer buffer LVGL's
    64KB heap couldn't satisfy (task watchdog hang), a faster
    matrix-transform path still fell back to the same slow buffer path
    whenever the redraw's dirty rect didn't cover the whole container
    (watchdog hang again), and once shrunk, the matrix path itself turned
    out to have a real bug combining with our custom
    LV_COLOR_FORMAT_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
    [gui_manager.hpp, main.cpp]
2026-08-25 Switch faces immediately, no settle wait
    The !is_moving gate on committing a face switch was a hedge against
    gyro angle overshoot during a flip (pre gyro-scale-fix/alpha-tuning, a
    fast rotation could transiently read 30-40 degrees past true). Now that
    the overshoot is fixed, the user tried committing immediately instead
    of waiting for is_moving to clear and preferred it on hardware —
    QuantizeFace's own 80-degree hysteresis already rejects resting noise
    on its own, so the extra gate was redundant on top of it.
    [app_controller.hpp]
2026-08-25 Simplify brightness notification: movement wakes it, brightness-only
    - UpdateBrightness() now also takes attitude.is_moving, folded into a
    single `interacting` flag alongside tap/flip-driven status edges — so
    spinning the device without crossing a face boundary keeps the screen
    bright instead of letting it fade out from under you.
    - Replaced the never-fully-realized breathing dark-bright-dark pulse
    with: focus-like phases ramp UP to full bright in the last ~30s
    (reaching it within ~3s, then holding), break phases stay fully bright
    the whole time. TimerFace::Status gained is_break_phase (a fact,
    PomodoroFace reports it, others default false) so AppController can
    tell the two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
    [app_controller.hpp]
2026-08-25 Add tap-mute window, initial angle seeding, gyro/accel low-pass filter
    - AppController: OnTap() ignores taps for kTapMuteAfterSwitchMs (1s)
    after a face switch, absorbing flip-induced tap-engine false triggers
    instead of letting them immediately start the timer — expected to
    matter more once the device is in an enclosure.
    - GuiManager: SetPrimaryText/SetRotationDeg now skip the LVGL call
    entirely when the value hasn't actually changed, and expose
    GetUpdateCount() (a real update counter, not a physical-flush count —
    root_ needs ~3 flush calls per logical redraw at its size, so counting
    flushes overstated the true rate by ~3x). main.cpp uses it to print a
    measured fps on th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
    [app_controller.hpp, gui_manager.hpp, main.cpp]
2026-08-25 Round sensor dt_ms, widen face-return hysteresis, tune tap-mute window
    - main.cpp: sensor_dt_ms now rounds to the nearest ms instead of
    truncating — truncation was a real, measured drift source (loses up to
    999us/tick systematically), worse at the current 120Hz sensor rate
    than when originally measured at ~2% slow. Confirmed on hardware: no
    drift against a phone stopwatch over 24+ minutes.
    - app_controller.cpp: kFaceHysteresisLeaveDeg 80 -> 70 -> 65 (return band
    now +-25 deg) — the new low-pass filter's convergence lag was landing
    the settled post-flip angle close enough to the old boundary to feel
    sluggish returning to a face.
    - Tap-mute window tuned 1000 -> 500ms after fi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
    [app_controller.hpp, main.cpp]
2026-08-25 Fix battery ADC divider ratio in hardware_pinout.md (100K:100K, not 200K:100K)
    Verified directly against the schematic (R4/R7 both 100K, VBAT-R4-BAT_ADC-R7-GND) after the user's own inspection disagreed with the documented value.
2026-08-25 Add phase accent colors, breathing outer ring, custom digit font
    - Primary text drops the "Focus"/"Break" word prefix in favor of a
    per-phase accent color (focus=red, break=green, count-up=blue) via
    new GuiManager::SetAccentColor(), applied to both the label and the
    new outer ring
    - Outer ring: a static (non-rotating, rotationally symmetric so it
    never touches the transform/matrix crash path) circular border,
    shown while paused, hidden while running, breathing (cosine opacity
    fade, derived from remaining_ms so it can't drift) in the last 5s of
    a phase with a target duration — replaces a first hard on/off blink
    version found too harsh on real hardware
    - Ring show/breathe thr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
    [app_controller.hpp, gui_manager.hpp]
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2026-08-30 Add BreathFace (D face's real function): guided 4-7-8 breathing exercise
    Resolves app_controller.hpp design note 4 ("D face has no defined
    behavior yet") — D now runs a guided breathing exercise (Ready? -> 4
    cycles of inhale/hold/exhale, durations ramping 2-3-4 -> 3-5-6 -> 4-7-8
    -> 4-7-8) instead of the ReservedFace placeholder, which is deleted (all
    four faces now have real behavior, no more slots left for it).
    - GuiManager gains a second small label (secondary_label_, Montserrat 18)
    stacked above the primary digits inside root_ — root_ grew from 60 to
    65px tall to fit both exactly, still far below anything that risked the
    original rotation-crash buffer-size class of bug. Used fo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
    [app_controller.hpp, gui_manager.hpp]
2026-08-31 Add multi-orientation accelerometer bias calibration
    RunCalibrationMode now collects 4 stationary, angularly-separated accel
    samples (via gyro-stillness detection + a minimum angular-separation
    check between captures) before the existing single-point face-A step,
    and averages them into an X/Y accel bias — the four points are 90
    degrees apart on what should be a circle around the origin, so their
    average cancels the true rotating signal and leaves just the fixed
    offset. No notion of "which face" is needed during that phase; the math
    only needs four sufficiently different orientations, not specific
    labels, so the flow never has to identify or prompt for a particular
    face.
    This corrects a re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
    [main.cpp]
2026-08-31 Split gyro/accel low-pass filter alphas; translate remaining comments to English
    - kLowPassAlpha split into kGyroLowPassAlpha (0.75, pushed further toward
    responsiveness — still felt laggy at the old shared 0.6) and
    kAccelLowPassAlpha (0.2, back toward heavier smoothing). They were
    sharing one constant, so raising it for gyro responsiveness was also
    quietly weakening accel's noise immunity, even though accel only ever
    contributes kComplementaryAlpha's 10%-per-tick correction — it was
    never the signal driving felt responsiveness, so there was no reason
    its filtering had to track gyro's. Confirmed on hardware: rotation
    stays responsive and hand-held vibration no longer read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
    [app_controller.hpp, gui_manager.hpp]
2026-09-01 Fix calibration mode's flow, on-screen legibility, and UI collisions
    Flow (calibration_mode.cpp):
    - Countdown moved to run first, not after the 4-point accel-bias flip
    sequence. Running it last meant a second, unexplained countdown fired
    right after the flips and locked in whichever face they happened to
    end on as the rotational reference ("face A") -- not the one the user
    actually meant, rotating the whole UI 90 degrees from what they
    expected (hardware report: B->C->D->A flip, then a surprise second
    countdown locked in A). Countdown first means exactly one calibration
    pass, and the reference is whatever face the user deliberately settled
    into before it started -- that posit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
    [main.cpp]
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2026-09-07 Add M9 idle sleep (light sleep + GPIO wake), fix rotation reversal, improve render throughput
    M9 idle sleep: after ~18s paused/idle, fade out and enter a blocking
    RunIdleSleep() loop (sleep_mode.cpp) that calls esp_light_sleep_start()
    directly with a real GPIO wakeup source on IMU_INT2 (tap events, CTRL8
    routes them there) plus a 1s timer backstop, waking paused and requiring
    a second tap to resume. Two automatic-PM-light-sleep-based approaches
    (edge ISR + gpio_wakeup_enable, then a PM light-sleep exit callback) hit
    real hardware problems along the way — an ISR livelock crash and a
    mysterious ESP_SLEEP_WAKEUP_UNDEFINED — both traced to the same cause
    (gpio_wakeup_enable() silently reprog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
    [app_controller.hpp, gui_manager.hpp, lgfx_config.hpp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]
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2026-09-07 Turn WoM's oversensitivity into a double-tap-to-wake feature
    Even with the WoM threshold register maxed out (kWomThresholdMg=255,
    its 8-bit ceiling), an incidental hand bump near the device was still
    enough to trigger a wake — the register alone had no more headroom
    left to fix this.
    RunIdleSleep()'s WoM trigger is now treated as a silent pre-wake:
    screen stays off, and the loop switches back to the tap engine to
    wait for a genuinely separate tap within a bounded window
    (kWomConfirmWindowMs, 500ms) before calling it a real wake. No
    confirming tap means straight back into WoM/light sleep.
    This ended up being a deliberate two-tap gesture rather than a plain
    debounce: on this hardware, a si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
    [app_controller.hpp, main.cpp]
2026-09-07 Gate loose debug prints behind flags; widen gyro range to +-512dps
    Log cleanup: PollWomEvent()/PollTapEvent()'s STATUS1 prints
    (qmi8658.hpp) and RunIdleSleep()'s SLEEP,... line (sleep_mode.cpp)
    had no on/off switch at all. Gave each its own local flag
    (kQmi8658DebugLogEnabled, kSleepDebugLogEnabled) rather than sharing
    kDebugOverlayEnabled — that one is on-screen UI, harmless to always
    leave on, while these are serial printf streams that compete for the
    same UART and are each useful at different times. Re-enabled
    kAttitudeDebugLogEnabled (angle CSV, for graphing) and turned off
    kLoopTimingLogEnabled (once-a-second perf breakdown) so a graphing
    session gets a clean stream instead of interle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
    [main.cpp, sleep_mode.cpp]
2026-09-08 Add battery-check gesture: pick up device, hold, see charge level
    Tilting the device out of the tracked rotation plane and holding it
    (AttitudeEstimator::Output::in_valid_plane false for 500ms) swaps the
    current face's display for a 5-band charge gauge; holding it back in
    the valid plane returns to normal immediately. Deliberately not a
    Face — the underlying timer keeps ticking underneath, nothing to
    save or restore going back out (same shape as idle sleep).
    in_valid_plane gained Schmitt-trigger hysteresis (enter at 0.9g,
    return at 0.5g) in AttitudeEstimator itself rather than in
    AppController, since AppController only ever sees the boolean, not
    the underlying |AZ| needed to build a band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
    [app_controller.hpp, gui_manager.hpp, main.cpp]
2026-09-11 Redesign outer ring as a per-face countdown/count-up progress indicator
    Replaces the old opacity-only ring with a three-layer lv_arc setup (dim
    full-circle track + bright progress arc + a straight radial tick at the
    moving boundary) shared by every TimerFace via Status.target_ms/
    is_count_up. Eroding (countdown) and growing (count-up) phases share one
    geometric primitive; the tick is hidden until a phase actually starts,
    solid while running, and hard-blinks while paused. Ring orientation is
    re-snapped once per face switch (SetRingOrientation), reusing the same
    kRotationSign convention as root_'s continuous counter-rotation rather
    than deriving a new one.
    BreathFace keeps its own bespoke ris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
    [app_controller.hpp, gui_manager.hpp]
2026-09-11 Redesign battery-check view as a horizontal battery icon
    Replaces the 5 full-width bands covering the whole round panel with a
    literal battery icon (gray outline + terminal nub, 5 vertical segments
    filling left-to-right) per the user's reference image. Fill color per
    level is unchanged (BatteryTierColor, red at 1 -> green at 5).
    [gui_manager.hpp]
2026-09-11 Fix ring tick thickness: decouple from ring width, fix start-of-phase clipping
    kRingTickThicknessPx is now its own tunable constant (9) instead of being
    derived from kRingWidthPx (7) — the two came out numerically equal but the
    tick still read visibly thinner on hardware, being a narrow-angle arc
    segment rather than the ring's own full sweep.
    Also fixes the tick rendering at roughly half its normal width for the
    first few seconds of every phase: its angular span was being clamped
    per-edge to stay within [0, 360], which silently dropped the left half
    whenever the countdown boundary sat near 0 degrees (true right as a phase
    starts running). Now shifts the whole span to stay in-bounds instea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
    [gui_manager.hpp]
2026-09-11 Flip screen rotation to CCW-positive; pin face A/C content to -90/90
    screen_angle_deg was CW-positive (flipped from CCW-positive back on
    2026-08-23), which turned out to be a mis-description of the intended
    convention, only caught once the on-screen debug angle was watched
    directly against physical rotation. Flips both the gyro integration term
    and the accel atan2 formula in AttitudeEstimator back to CCW-positive,
    with GuiManager's kRotationSign flipped in lockstep so root_/ring_
    rendering is unaffected — same rendered rotation for any given physical
    orientation, only the raw angle's sign changes.
    AngleFromAccel's new formula (atan2(ax,-ay), offset added instead of
    subtracted) is the exac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
    [app_controller.hpp, gui_manager.hpp]
2026-09-11 Add real battery ADC reading, replacing the battery-gauge stub
    New BatteryMonitor (GPIO1/ADC1_CH0, esp_adc oneshot + curve-fitting
    calibration) replaces AppController's kStubBatteryFilledBlocks. Read once
    per second (main.cpp), not every sensor tick — voltage has no reason to
    be that fresh. AppController::BatteryVoltageToFilledBlocks() maps the
    LiPo's 3.0-4.2V usable range linearly across GuiManager's 5 gauge blocks.
    Debug overlay gained Bat/Raw fields to make the calibration process
    itself hardware-visible rather than guessed at. That process caught a
    real averaging bug (dividing by the nominal sample count instead of the
    actual number of successful ADC reads, silently under-reporting vo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
    [app_controller.hpp, battery_monitor.cpp, main.cpp]
2026-09-11 Widen WoM double-tap confirm window to fix enclosure wake reliability
    kWomConfirmWindowMs was 500ms, tuned on the bare board with a note that it
    hadn't been re-tested against the finished enclosure. Inside the
    enclosure it took ~4 taps instead of the usual 2 to wake the device,
    despite the same tap force still reliably registering during normal
    pause/resume — ruling out the tap engine's own sensitivity thresholds.
    Widened to 1500ms; confirmed fixed on real hardware, both bare-board and
    in the enclosure.
    Also added a one-off latency measurement (kWomConfirmLatencyLogEnabled)
    to check a competing hypothesis — a slow WoM-to-tap-engine transition.
    Measured ~13.45ms, small enough to rule out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
    [main.cpp]
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2026-09-12 Add stage 2 of the low-battery safety net: forced deep sleep
    Below AppController::kCriticalBatteryEnterV (3.0V), the device now
    forces a real esp_deep_sleep_start()/reboot instead of just showing the
    stage-1 warning screen, with hysteresis (exit at 3.8V) wide enough to
    survive a charging-induced IR voltage jump, RTC-memory-persisted state
    so a minimal boot can recheck voltage before doing any heavy init, and
    a BOOT-button escape hatch.
    Two gaps closed after further review:
    - The stage-1 warning screen's countdown-to-sleep could be reset
    indefinitely by motion or a tap once voltage was already critical,
    letting a device be kept awake below the safe threshold.
    - RunIdleSleep()'s light-sle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
    [app_controller.hpp, main.cpp, sleep_mode.cpp]
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2026-09-12 Trim narrative comments across firmware/main to functional explanations
    Comments had accumulated into a running development log — dated
    iteration history, quoted hardware-test feedback, chronologies of
    abandoned attempts — turning most files into something closer to a lab
    notebook than source code meant for others to read. Rewrote comments
    throughout to state the current design and the non-obvious WHY only,
    dropping the R&D narration; history like that belongs in commit
    messages and the project's own reference docs, not inline.
    Comment-only change: build output is byte-identical (same binary size),
    confirming no logic moved. Also fixed one stale comment found in the
    process (qmi8658.hpp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
    [app_controller.hpp, battery_monitor.cpp]
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
